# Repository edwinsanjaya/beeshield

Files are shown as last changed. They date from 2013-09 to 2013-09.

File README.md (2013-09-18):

# Beeshield

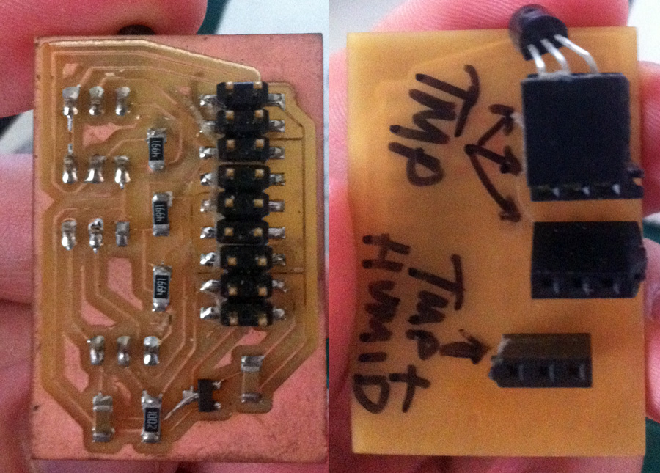
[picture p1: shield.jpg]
Shield image


## Sensors

This 'shield' connects the following sensors to the Smart Citizen base kit - [input pin wiki page](https://github.com/fablabbcn/Smart-Citizen-Kit/wiki/Making-a-Shield)

* 1 x DHT22 Temperature and Humidity Sensor
* 3+ x DS18B20 Digital Temperature Sensors

The three inputs for the DS18B20 aren't actually necessary, although the board works perfectly fine using them as-is, you can daisy-chain loads of these sensors together meaning that they only require a single input pin. They are a relic from using previous sensors and time constraints meant that they stayed as 3 pins.

The DHT22 is a strange beast. There are different versions of it. Some will happily run at 3.3V, the ones that I encountered will only run at 5V, however, there is a 'hack'. If you flagrantly ignore the following datasheet diagram

dht22 pins

 and connect pin 3 to ground, along with pin 4, it seems to work. Keep in mind that this is a very slow sensor, I wouldn't recommend taking readings from it any faster than once every few seconds.
 
## Connections

You may notice that 2 of the last pins on the 12 pin connection aren't actually connected to anything, it's just that there are 6 pins on each header. By all means use 10 pins instead.

## Milling

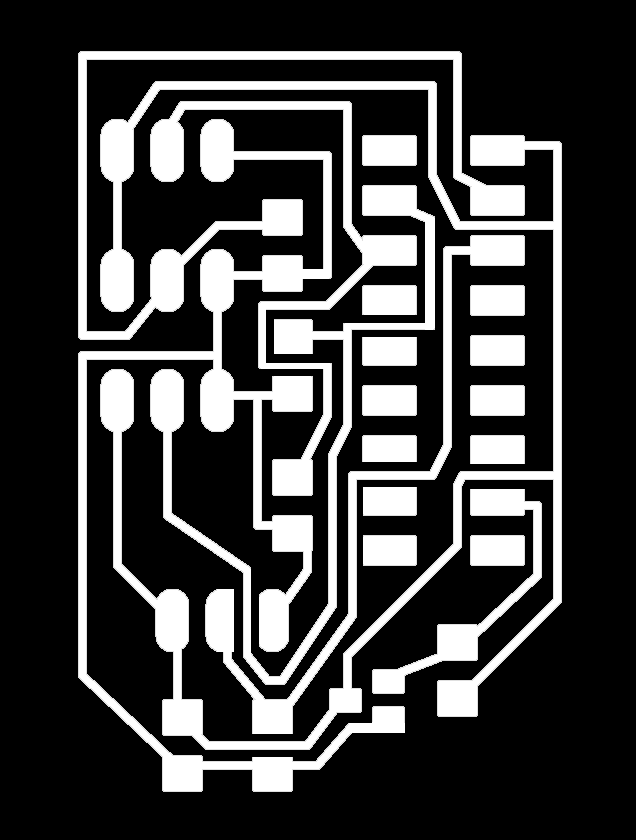
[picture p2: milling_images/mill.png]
Milling profile

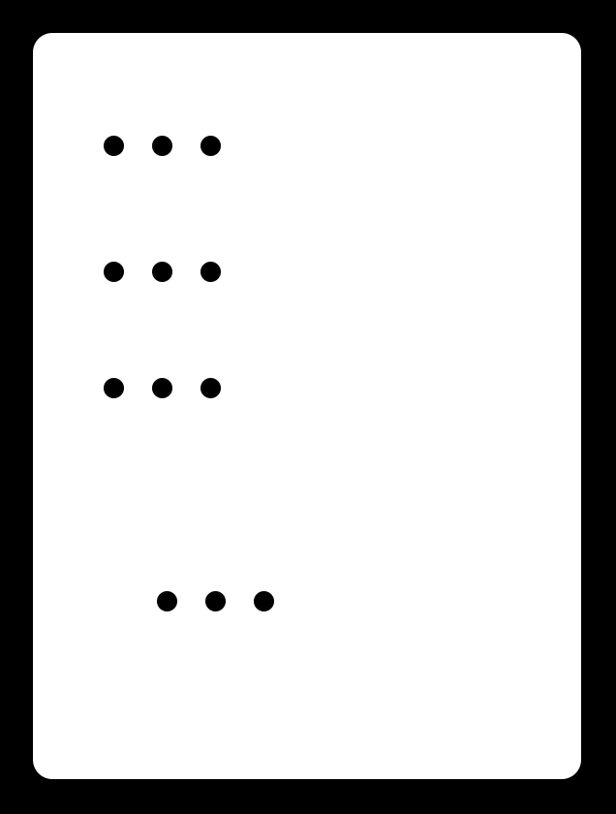
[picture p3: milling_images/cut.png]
Cutting profile


I haven't tested the circuit PNGs above and my memory is a bit rusty. Please check that the borders are ok and that they are a reasonable size (in mm) in Fab Modules before milling.

## Misc

Feel free to ignore the `misc` folder, I was just dumping related stuff in there.

### Other Information

You may? find some insights here although I was quite delirious from lack of sleep when the page was written!
[http://academy.cba.mit.edu/2013/students/rees.john/input-devices/](http://academy.cba.mit.edu/2013/students/rees.john/input-devices/)

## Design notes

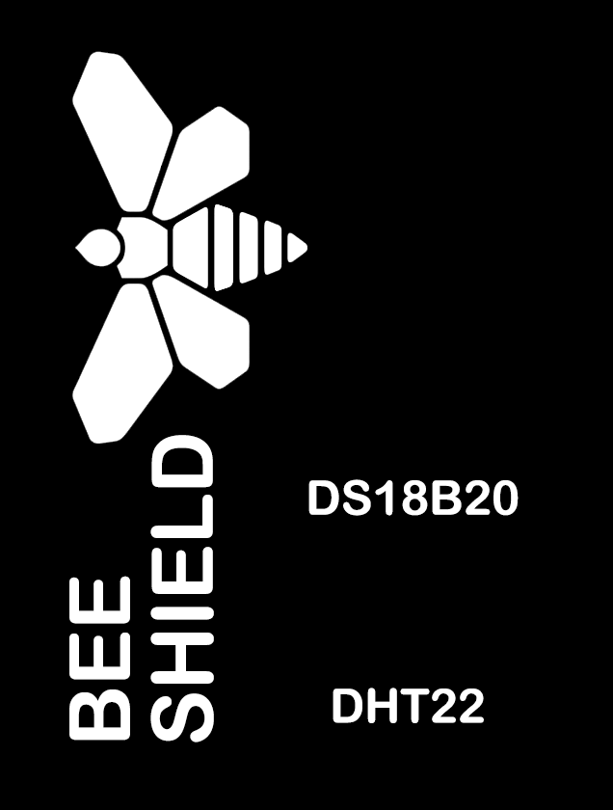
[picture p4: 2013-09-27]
milling_images/back.png

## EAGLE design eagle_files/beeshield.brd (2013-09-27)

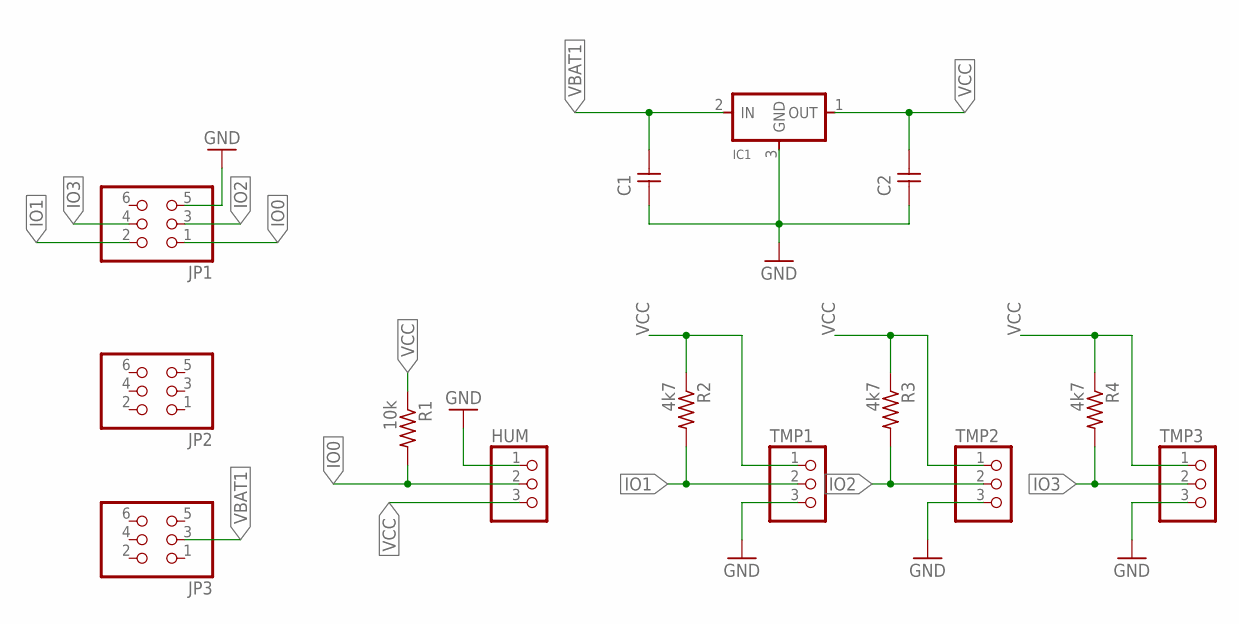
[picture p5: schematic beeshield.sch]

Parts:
C1, C2: UNPOLARIZED_CAPACITOR1206; 1206
HUM: PINHD-1X3; 1X03
IC1: REGULATORSOT23; SOT23
JP1, JP2, JP3: PINHD-2X3-SMD; 2X03SMD
R1: 10k; 1206
R2, R3, R4: 4k7; 1206
TMP1, TMP2, TMP3: PINHD-1X3; 1X03

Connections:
GND: C1.1, C2.1, HUM.1, IC1.3 (GND), JP1.5, TMP1.3, TMP2.3, TMP3.3
IO0: HUM.2, JP1.1, R1.2
IO1: JP1.2, R2.2, TMP1.2
IO2: JP1.3, R3.2, TMP2.2
IO3: JP1.4, R4.2, TMP3.2
VBAT1: C1.2, IC1.2 (IN), JP3.3
VCC: C2.2, HUM.3, IC1.1 (OUT), R1.1, R2.1, R3.1, R4.1, TMP1.1, TMP2.1, TMP3.1

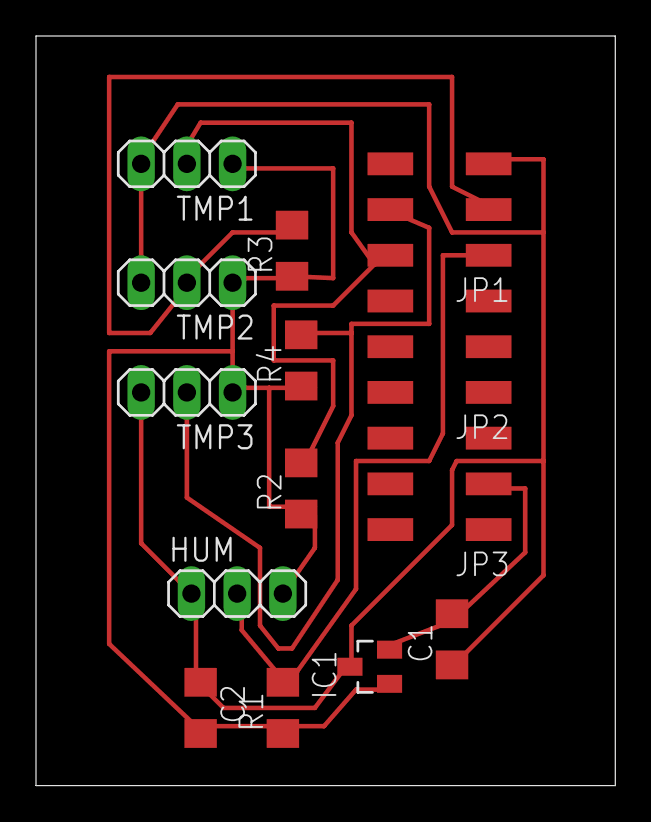
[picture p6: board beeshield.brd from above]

Board: 2 copper layers, 32.2 x 41.6 mm, 14 parts (0 on the bottom side), 7 nets.

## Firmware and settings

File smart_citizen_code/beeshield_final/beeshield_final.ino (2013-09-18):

#include "DHT.h"
DHT dht(13, DHT22);

#include <Wire.h>
#include <RTClib.h>
RTC_Millis RTC;

#include <OneWire.h>
#include <DallasTemperature.h>

OneWire oneWire0(5);
DallasTemperature sensor0(&oneWire0);

OneWire oneWire1(9);
DallasTemperature sensor1(&oneWire1);

OneWire oneWire2(10);
DallasTemperature sensor2(&oneWire2);

#include <SD.h>
File myFile;

void setup() {
  Serial.begin(9600);
  
  while (!Serial);

  if (!SD.begin(11)) {
    Serial.println("SD initialization failed!");
    return;
  }
  Serial.println("SD initialization done.");
  
  sensor0.begin();
  sensor1.begin();
  sensor2.begin();
  RTC.begin(DateTime(__DATE__, __TIME__));
}

void loop () {

  float h = dht.readHumidity();
  float t = dht.readTemperature();  

  DateTime now = RTC.now();
  String filename = "";
//  filename += now.year();
  String month = String(now.month());
  if (now.month() < 10) {
    month = "0" + month;
  }
  String day = String(now.day());
  if (now.day() < 10) {
    day = "0" + day;
  }
  String hour = String(now.hour());
  if (now.hour() < 10) {
    hour = "0" + hour;
  }
//  String minute = String(now.minute());
//  if (now.minute() < 10) {
//    minute = "0" + minute;
//  }
  filename += month;
  filename += day;
  filename += hour;
//  filename += minute;
  filename += ".csv";

  char __dataFileName[filename.length() + 1];
  filename.toCharArray(__dataFileName, sizeof(__dataFileName));
  Serial.println("");
  Serial.println(__dataFileName);
  
  myFile = SD.open(__dataFileName, FILE_WRITE);
  if (myFile) {
    sensor0.requestTemperatures();
    sensor1.requestTemperatures();
    sensor2.requestTemperatures();
    Serial.println(sensor0.getTempCByIndex(0));
    Serial.println(sensor1.getTempCByIndex(0));
    Serial.println(sensor2.getTempCByIndex(0));
    Serial.println(t);
    Serial.println(h);
    myFile.print(sensor0.getTempCByIndex(0));    
    myFile.print(",");
    myFile.print(sensor1.getTempCByIndex(0)); 
    myFile.print(",");
    myFile.print(sensor2.getTempCByIndex(0)); 
    myFile.print(",");
    myFile.print(t); 
    myFile.print(",");
    myFile.print(h);
    myFile.print(",");
    myFile.println(now.get());
  } else {
    Serial.println("FAIL");
  }
  myFile.close();

  delay(120000);
};

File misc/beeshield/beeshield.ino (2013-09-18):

#include "DHT.h"
//#include <Wire.h>

#define DHTPIN A2
//#define DHTTYPE DHT11   // DHT 11 
#define DHTTYPE DHT22   // DHT 22  (AM2302)
//#define DHTTYPE DHT21   // DHT 21 (AM2301)
DHT dht(DHTPIN, DHTTYPE);

//#include "I2C_Anything.h"
typedef struct {
  float h;
  float t;
} Vals;
Vals v;

void setup()
{
//  Wire.begin(5);
//  Wire.onRequest(requestEvent);
  dht.begin();
}

void loop()    
{
  // Reading temperature or humidity takes about 250 milliseconds!
  // Sensor readings may also be up to 2 seconds 'old' (its a very slow sensor)
  getValues();
  delay(100);
}

void getValues()
{
  v.h = dht.readHumidity();
  v.t = dht.readTemperature();
}

void requestEvent()
{
  if (isnan(v.t) || isnan(v.h))
  {
//    Wire.write(0);
  } else
  {
//    I2C_writeAnything(v);
  }
}

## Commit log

2013-09-27 new milling image
2013-09-27 new eagle files
    [beeshield.brd, beeshield.sch]
